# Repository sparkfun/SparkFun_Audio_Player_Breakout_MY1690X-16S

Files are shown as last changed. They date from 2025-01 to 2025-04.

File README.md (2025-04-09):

SparkFun Audio Player Breakout - MY1690X-16S
========================================

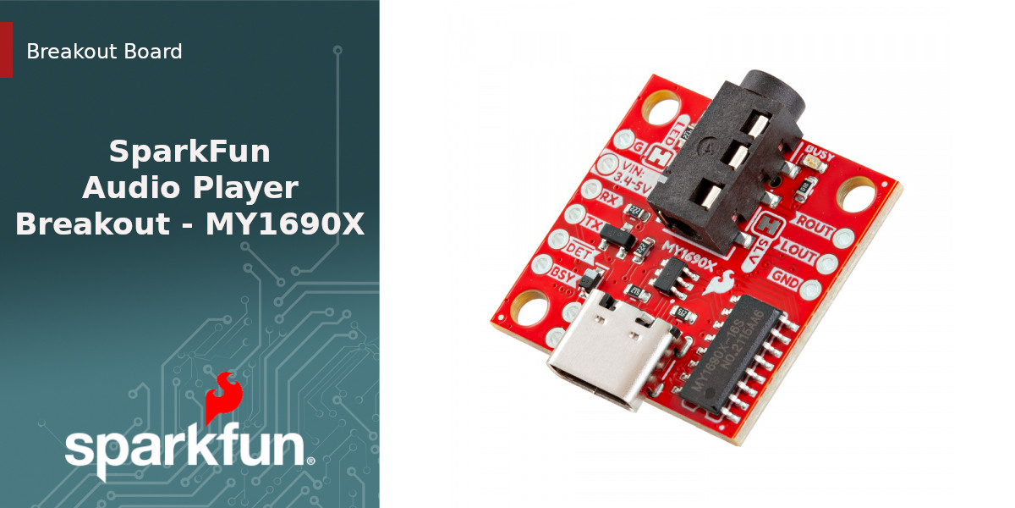
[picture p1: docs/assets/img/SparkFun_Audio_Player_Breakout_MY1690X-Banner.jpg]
SparkFun Audio Player Breakout - MY1690X-16S (https://www.sparkfun.com/sparkfun-audio-player-breakout-my1690x-16s.html)


[*SparkFun Audio Player Breakout - MY1690X-16S (BOB-28038)*](https://www.sparkfun.com/sparkfun-audio-player-breakout-my1690x-16s.html)

The SparkFun M71690X-16S Audio Player Breakout is a compact serial-controlled audio player designed around the MY1690X-16S decoder that supports both .WAV and .MP3 audio files played from a connected microSD card formatted to FAT16 or FAT32. The board includes a USB-C connector to mount it as a removable USB drive on a connected computer, a µSD card slot for connecting a compatible SD card, and a 3.5mm TRRS connector for headphone audio output.

Repository Contents
-------------------

* **.github/workflows** - YAML files used for GitHub Actions and GitHub Pages/mkdocs
* **/Hardware** - KiCad design files (.kicad_pcb, .kicad_sch, .kicad_pro)
  * **/Production** - Production panel files (.kicad_pcb)
* **/docs** - Online documentation files
  * **/assets** - Folder containing all the file assets used for product documentation
    * **/board_files** - Copy of design files used for product documentation
    * **/component_documentation** - Datasheets and manuals for hardware components
    * **/img** - Images for product documentation
  * **/github** - Files stating how to contribute and filing issues used for product documentation
  * **/javascript** - Folder containing custom javascript used for product documentation
  * **/stylesheet** - Folder containing CSS files used for product documentation
* **/overrides** - Customization files used for product documentation
  * **/.icons** - Icons used for GitHub used for product documentation
  * **./partials** - Used for product documentation

Documentation
--------------
* **[SparkFun MY1690X MP3 Decoder Arduino Library](https://github.com/sparkfun/SparkFun_MY1690_MP3_Decoder_Arduino_Library)** - Arduino library for the MY1690X MP3 Decoder.
* **[Hookup Guide](https://docs.sparkfun.com/SparkFun_Audio_Player_Breakout_MY1690X-16S)** - Basic hookup guide for the SparkFun Serial Audio Player Breakout - MY1690X.

Product Versions
----------------
* [BOB-28038](https://www.sparkfun.com/sparkfun-audio-player-breakout-my1690x-16s.html) - v1.0

License Information
-------------------

This product is _**open source**_!

Please review the LICENSE.md file for license information.

If you have any questions or concerns on licensing, please contact technical support on our [SparkFun forums](https://forum.sparkfun.com/viewforum.php?f=152).

Distributed as-is; no warranty is given.

- Your friends at SparkFun.

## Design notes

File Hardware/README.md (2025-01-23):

SparkFun <PRODUCT NAME> Design Files
=====================================

The .sch and .brd files hare are Eagle CAD schematic and PCB design files from SparkFun Electronics.
A freeware version of Autodesk Eagle can be found [here](https://www.autodesk.com/products/eagle/free-download).

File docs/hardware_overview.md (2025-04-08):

Let's take a closer look at the SparkFun Audio Player Breakout - MY1690X and the hardware present on the board. The photo below highlights the major components on this shield that we'll cover in more detail in this section:

<center>
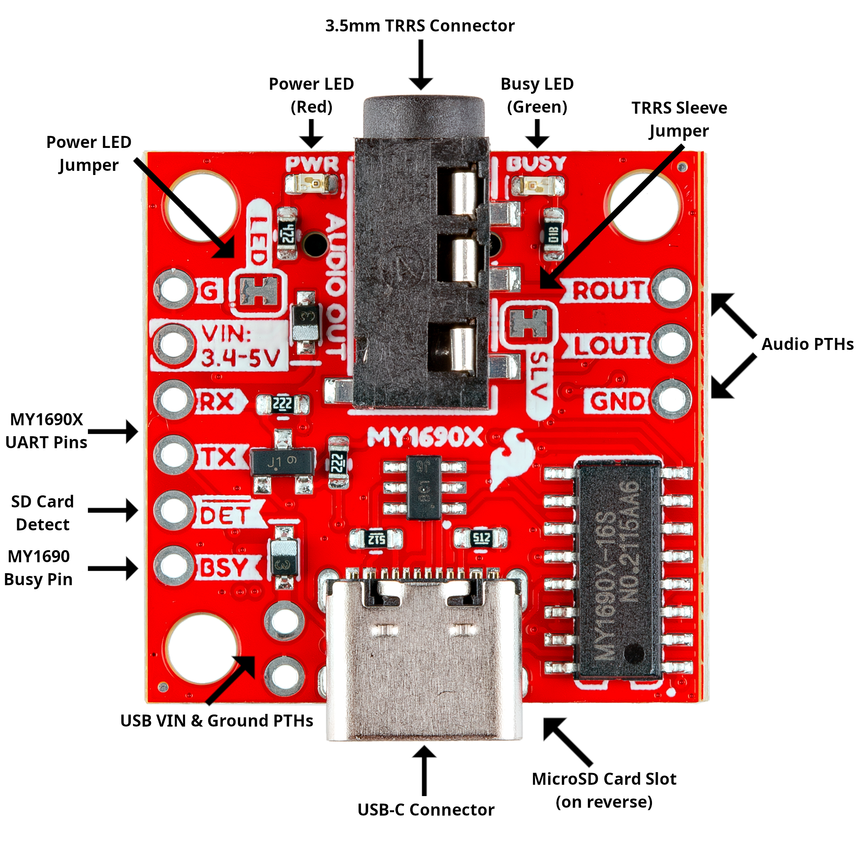
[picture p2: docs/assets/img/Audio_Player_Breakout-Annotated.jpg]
Annotated photo of audio player breakout

</center>

## MY1690X MP3 Decoder IC

The MY1690X is an MP3 decoder IC that works with both MP3 and WAV audio files stored on a connected &micro;SD card. The MY1690X can function both as a removable USB drive when connected over USB to load, view or edit files on the SD card. The IC operates over a serial-UART interface at 3.3V TTL using a command set to control audio playback (Play, Pause, Next, etc.), volume and equalizer settings and query statuses (SD card contents, track name/length, etc.). It supports audio files with sampling rates between 8 and 48k with bit rates between 8 and 320Kbps.

## Connectors

The Audio Player Breakout - MY1690X has a pair of connectors on the board. A USB-C connector and 3.5mm TRRS connector.

### USB-C

The USB-C connector on the board connects directly to the MY1690X to mount it as a removable USB drive when a microSD card is inserted and the board is plugged into a computer. This allows you to directly add and remove audio files to a connected microSD card. This works great for small audio files but in our testing we found the transfer speed is quite slow and can take several minutes to upload larger audio files. We recommend uploading large files using a USB SD card reader or directly connecting your SD card to your computer.

When connected over USB-C (and with a microSD card plugged in) the MY1690X will stay in USB drive "mode" until a power cycle. The MY1690X does not have a Reset line so either unplug the board or press the RESET button on the shield to cycle power.

## Audio Output

The shield routes the audio output from the MY1690X to a 3.5MM TRRS audio connector as well as three 0.1"-spaced through hole pins. This allows you to easily plug in a pair of headphones directly to the shield or solder an alternate audio output. Note, the MY1690X can easily output audio for small headphones but you'll need an external amplifier on the audio output to drive larger speakers.

## MicroSD Card Slot

The audio player breakout's microSD card slot works with most standard SD cards that have up to 32GB storage space and formatted to FAT16 or FAT32. The MY1690X requires specific naming of files and folders stored on the card. Read on to the MicroSD Card Setup section of this guide for detailed information on naming conventions.

## Power

The Audio Player Breakout has two primary ways for powering during normal (not USB drive) operation through the **VIN** and **VUSB** PTHs. Both of these pins are netted with VCC for the MY1690X and **3.4 and 5V**. The **VUSB** pin is also tied to the USB-C connector so it can be used either as a 5V power output with USB-C connector or as a power input while USB-C is **not** connected.

The USB-C connector can provide power to the board but the MY1690X defaults to operate as a removable drive when it detects a connection to the D+/- pins USB signals. 

## Pinout

The board breaks out the MY1690X's serial-UART pins (TX and RX), SD card detect, busy signal and power pins (VIN and GND) on one side and the audio output (Left, Right and Ground) on the opposite side. It also includes pins for VUSB and Ground next to the USB-C connector. The MY1690X communicates at 3.3V but the board has built-in level shifting to work with 5V logic boards.  

## LEDs

The board has a pair of LEDs labeled **PWR** and **BUSY**. The red Power LED indicates when the board has power. The green Busy LED indicates when the MY1690X is busy playing audio.

## Solder Jumpers

The Audio Player Breakout has three solder jumpers labeled **BUSY**, **PWR** and **SLV**. The **BUSY** and **PWR** solder jumpers complete the circuit for their respective LEDs and are CLOSED by default. Open them to disable these LEDs. The **SLV** jumper connects the sleeve pin of the TRRS connector to ground and is CLOSED by default. Open this jumper to free up the sleeve of the TRRS connector/cable. Most headphones with built-in mics send the MIC signal on the sleeve of their TRRS connector.

## Board Dimensions

The Audio Player Breakout measures 1" x 1" (25.4mm x 25.4mm) with three mounting holes that fit a [4-40 screw](https://www.sparkfun.com/screw-phillips-head-1-4-4-40-10-pack.html).

<center>
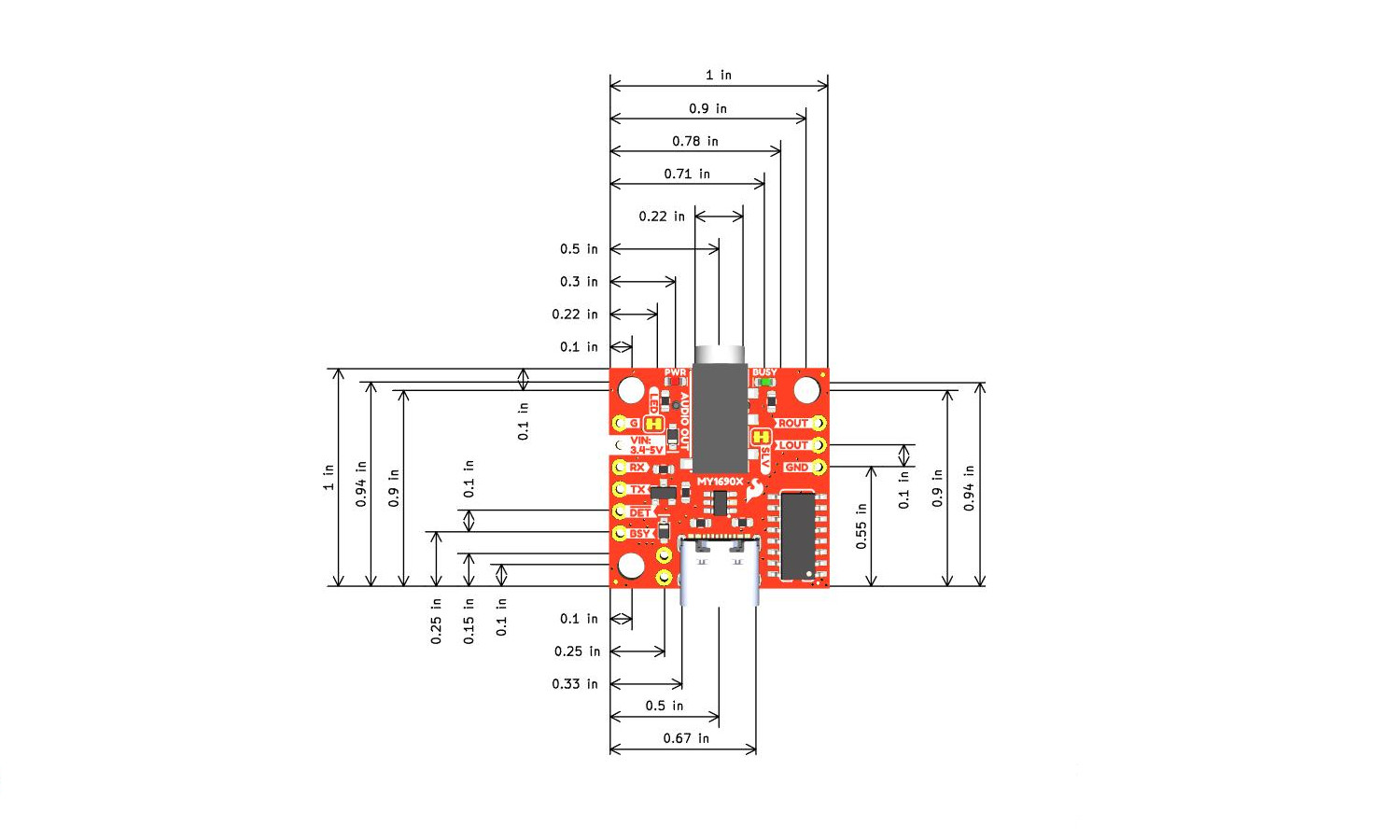
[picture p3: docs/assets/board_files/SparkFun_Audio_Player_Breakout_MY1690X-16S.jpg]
Board dimensions

</center>

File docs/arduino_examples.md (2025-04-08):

The SparkFun MY1690 MP3 Decoder Arduino library includes three examples to demonstrate how to use the library. Let's take a closer look at these examples.

## Example 1 - Play File

The first example plays the first audio track stored on a connected SD card once through and stops. In Arduino, open the example by navigating to **File** > **Examples** > **SparkFun MY1690X MP3 Decoder Arduino Library** > **Example1_PlayFile**. Select the **Board** and **Port** and click "Upload". Once upload finishes, the code will automatically start by playing the first track stored on the SD card so make sure to have headphones/speakers connected to hear the audio as it does not repeat. You can push the Reset button on the shield to reset the board and start the code over to hear the track play again.

The code does have some serial printouts to help troubleshoot if the code hangs on attempting to initialize the MY1690X or when checking the SD card for audio tracks. If you have any issues with playback, open the [serial monitor](https://docs.arduino.cc/software/ide-v2/tutorials/ide-v2-serial-monitor/) with the baud set to **115200** to view the serial prints from the code.

## Example 2 - Kitchen Sink

The second example demonstrates how to use all of the available commands on the MY1690X to control and manipulate audio tracks through a serial menu. Open the example by navigating to **File** > **Examples** > **SparkFun MY1690X MP3 Decoder Arduino Library** > **Example2_KitchenSink**. Select the **Board** and **Port** and click "Upload". After the code finishes uploading, open the serial monitor with the baud set to **115200** and you should see a menu like the screenshot below:

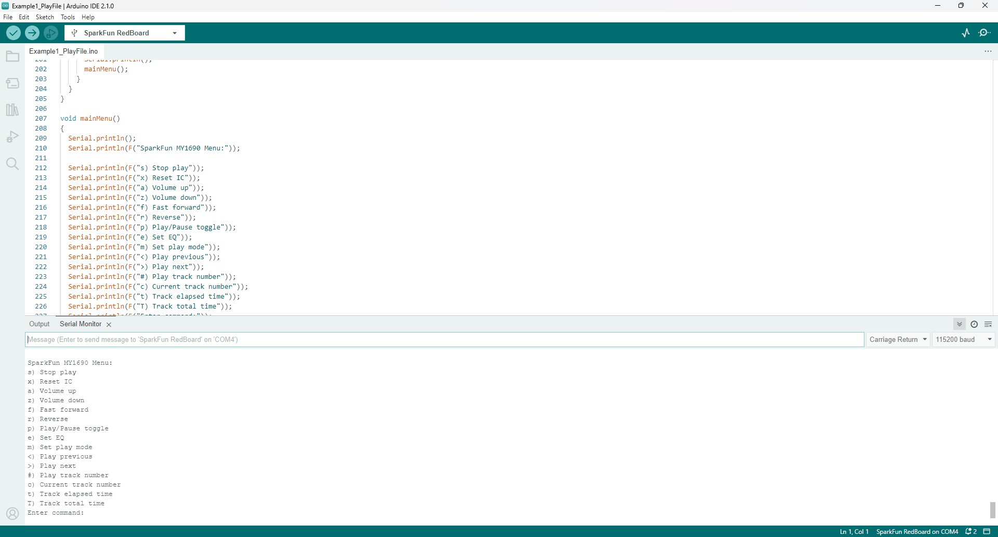
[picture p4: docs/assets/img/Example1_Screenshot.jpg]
Screenshot of example 2 serial menu


The MY1690 Menu has options for all the available playback and settings commands for the MY1690X. Some like "Play" or "Reverse" are straightforward and perform the expected action. The options for setting the equalizer (Set EQ) and play mode (Set Play Mode) cycle through the available options for these settings and print out the matching number. The Equalizer and Play modes are listed below and can be found in the instruction list in section 6.1 of the [MY1690X datasheet](./assets/component_documentation/MY1690X‑16S%20MP3%20Decoder%20IC%20User%20Manual.pdf):

**Equalizer Modes**

* 0 - None
* 1 - Pop
* 2 - Rock
* 3 - Jazz
* 4 - Classic
* 5 - Bass

**Play Modes**

* 0 - Full
* 1 - Folder
* 2 - Single
* 3 - Random
* 4 - No Loop

## Example 3 - Kitchen Sink ESP32

Example 3 - Kitchen Sink ESP32 is nearly identical to Example 2 but is modified to work with ESP32-based development boards like the [SparkFun IoT RedBoard - ESP32](https://www.sparkfun.com/sparkfun-iot-redboard-esp32-development-board.html). Open the example by navigating to **File** > **Examples** > **SparkFun MY1690X MP3 Decoder Arduino Library** > **Example2_KitchenSink**. Select the **Board** (SparkFun IoT RedBoard - ESP32 or other ESP32 dev board) and **Port** and click "Upload". After the code finishes uploading, open the serial monitor with the baud set to **115200** to view the same serial menu as pictured above.

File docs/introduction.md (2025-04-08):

Banner photo for Audio Player Breakout - MY1690X

The SparkFun Audio Player Breakout - MY1690X is a compact audio player built around the MY1690X audio decoder IC. The MY1691X supports both .WAV and .MP3 audio files stored on a connected microSD card with up to 32GB capacity and formatted to FAT16 or FAT32. The MY1690X communicates over serial UART with a simple command set 

You'll need the following items to follow along with this tutorial:

* [SparkFun Audio Player Breakout - MY1690X](https://www.sparkfun.com/sparkfun-audio-player-breakout-my1690x.html)
* [SparkFun RedBoard Plus](https://www.sparkfun.com/sparkfun-redboard-plus.html) or other development board
* [Male Breakaway Headers](https://www.sparkfun.com/male-breakaway-headers.html) or other header type
* [USB-C Cable](https://www.sparkfun.com/reversible-usb-a-to-c-cable-0-8m.html)

This breakout does require soldering to work properly so you'll need a soldering iron and soldering accessories to assemble it into an Arduino circuit.

## Topics Covered

This document contains three main sections: **Quickstart Guide**, **Hardware** and **Software**. 

The Quickstart Guide assumes a working knowledge of how to assemble and use breakout boards with an Arduino development board along with the required software to program them for your project's needs. It covers a quick assembly and then jumps right into getting the necessary software packages installed to start uploading code in just a few short minutes.

The Hardware pages cover a hardware overview that provides a detailed overview of the Audio Player Breakout - MY1690X covering all the major components on the board in detail as well as a hardware assembly page which goes over the steps required to assemble and use the Audio Player Breakout with an Arudino board.

The Software pages give instructions on installing the SparkFun MY1690 MP3 Decoder Arduino and using the examples included in it.

## Resources and Documentation

You'll find the board design files (KiCad files & schematic), relevant documentation (datasheets, white papers, etc.) and other helpful links in the **Resources**. Lastly, the **Support** section includes a Troubleshooting page that includes any helpful tips specific to this board as well as information on how to receive technical support from SparkFun.

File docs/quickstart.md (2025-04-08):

In this Quick Start guide we'll connect the SparkFun Audio Player Breakout - MY1690X to a SparkFun RedBoard Plus and use the SparkFun MY1690X MP3 Decoder Arduino Library to play audio stored on a connected microSD card. 

If you're not familiar with using breakout and development boards or the Arduino IDE, refer to the [Hardware](./hardware_overview.md) & [Software](./arduino_setup.md) sections for a detailed overview of the board along with instructions on soldering to and connecting the breakout, installing and using the SparkFun MY1690X MP3 Decoder Arduino Library.

## Basic Assembly

Start by soldering your preferred connector or wire to the to the power and serial pins (GND, VIN, RX and TX) on the Audio Player Breakout. We opted to just solder to all the pins to plug it into a breadboard for easy prototyping like the photo below:

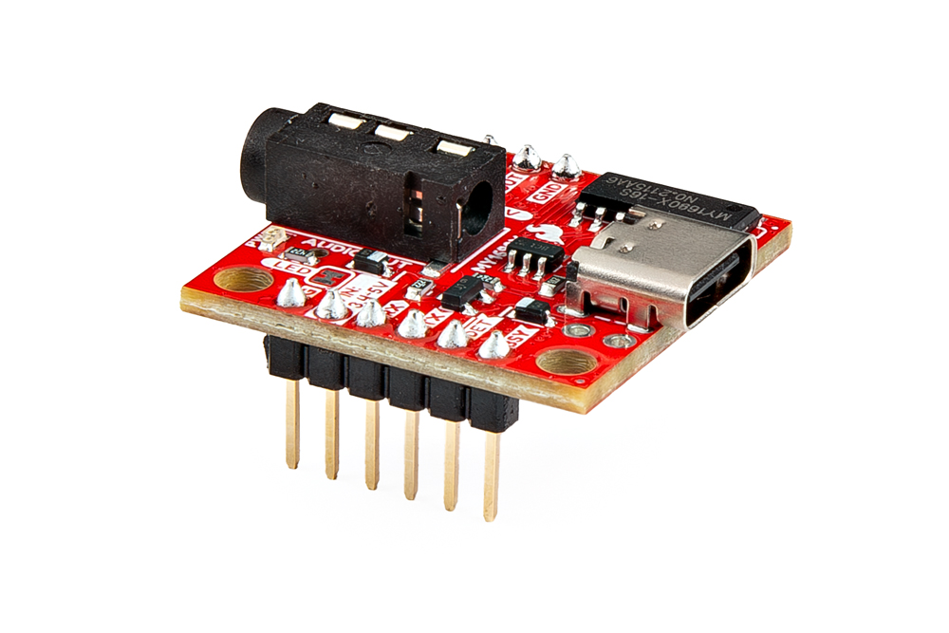
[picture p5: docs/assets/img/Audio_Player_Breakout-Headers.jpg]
Photo showing header pins soldered to the Audio Player Breakout


Next, make the following connections to your Arduino development board:

| Audio Player | Arduino |
| --- | --- |
| Ground | Ground  |
| VIN | 5V |
| RX | D9 |
| TX | D8 |

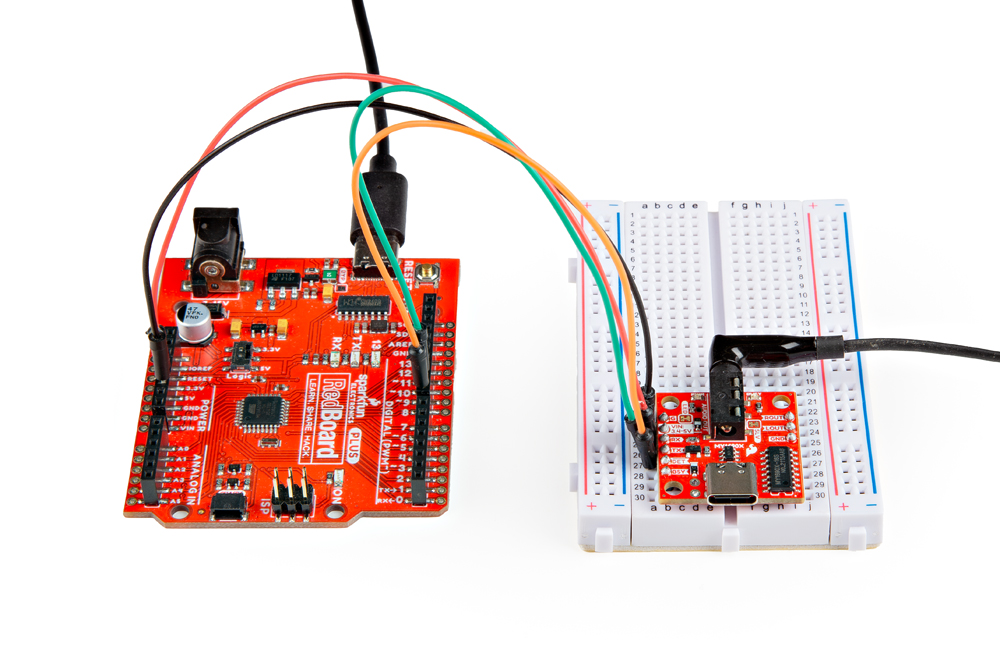
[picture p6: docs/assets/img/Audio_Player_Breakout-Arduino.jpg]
Photo showing Audio Player Breakout connected to RedBoard Plus


With everything wired up we can move on to preparing the SD card and uploading the example code.

## Prepare SD Card

The MY1690X works with standard SD cards up to 32GB capacity and formatted to either FAT16 or FAT32. Users can upload files to an SD card mounted on the shield by plugging it into a computer over USB-C or can load them directly onto the SD card using a USB Card Reader or the SD card slot on their computer. Files and folders on a connected SD card should match the following naming conventions:

* .MP3/.WAV files in the root directory must begin with a four digit number (eg. 000#) starting at 0001 and can have characters following the numbers
* Folders should begin with a two digit number (eg. 0#) starting at 01 and can have characters following the numbers.
* .MP3/.WAV files stored inside folders must begin with three digits (eg. 00#) starting at 001 and can have characters following the numbers.

Make sure to load the audio tracks onto the SD card, insert the card into the microSD card slot and then proceed to the Arduino Example.

## Arduino Example

With the audio player breakout connected to your development board, let's upload Example 2 - Kitchen Sink to the board to start playing and controlling audio. This example will start playing the first track once it's uploaded and also includes a serial menu to access all of the UART commands using simple text commands. Follow the steps below to upload the example.

* Open the [Arduino IDE](https://docs.arduino.cc/software/ide-v2/tutorials/getting-started-ide-v2/).
* Open the [Library Manager](https://docs.arduino.cc/software/ide-v2/tutorials/ide-v2-installing-a-library/) tool, search for "SparkFun MY1690X MP3 Decoder" and install the latest version 
* Open "Example 2 - Kitchen Sink".
* Select your Board (SparkFun RedBoard or other board) and Port and click "Upload".
* After the code compiles and finishes uploading, open the [serial monitor](https://docs.arduino.cc/software/ide-v2/tutorials/ide-v2-serial-monitor/) with the baud set to **115200**.
* The code prints out a menu of available commands to control the MY1690X's playback. Type in the command you'd like to do and hit Enter or click Send.
* Have fun playing around controlling track playback, volume and other features.

Screenshot of example 1 in Arduino

### Code to Note

* Serial Setup
``` c++
#include "SoftwareSerial.h"
SoftwareSerial serialMP3(8, 9); //RX on Arduino connected to TX on MY1690's, TX on Arduino connected to the MY1690's RX pin

//For boards that have multiple hardware serial ports
//HardwareSerial serialMP3(2); //Create serial port on ESP32: TX on 17, RX on 16
```
The code has options for both Software Serial and Hardware Serial depending on your dev board. The code defaults to use pins D8 and D9 for software serial

* MY1690X & Track Checks

```c++
if (myMP3.begin(serialMP3) == false) // Beginning the MP3 player requires a serial port (either hardware or software)
  {
    Serial.println(F("Device not detected. Check wiring. Freezing."));
    while (1);
  }

  int songCount = myMP3.getSongCount();
  if (songCount == 0)
  {
    Serial.println(F("Oh no! No songs found. Make sure the SD card is inserted and there are MP3s on it. Freezing."));
    while (1);
  }
```
On setup, the code checks to detect the MY1690X over serial and also checks to make sure the SD card has audio tracks 

* Get Track Numbers, MY1690 Version and Play First Track
```c++
  Serial.print(F("Number of tracks on SD card: "));
  Serial.println(songCount);

  Serial.print(F("MY1690 Version: "));
  Serial.println(myMP3.getVersion());

  myMP3.play(); //Will play the lowest numbered song in the folder
```

The example will print out the number of tracks detected on the SD card, the MY1690 version and then will play the lowest numbered song on the card. Note, it takes ~30ms for a track to start playing so the code waits 50ms before requesting play status.

* MY1690X Menu Options

This menu shows the available commands to control playback. Type in the matching character in the serial monitor and hit Enter to send it. The Set EQ and Set play mode commands cycle through the available equalizer and play mode options. Refer to the Arduino Examples section of this guide or section 6.1 of the [datasheet](./assets/component_documentation/MY1690X‑16S%20MP3%20Decoder%20IC%20User%20Manual.pdf) for more information.

```c++
void mainMenu()
{
  Serial.println();
  Serial.println(F("SparkFun MY1690 Menu:"));

  Serial.println(F("s) Stop play"));
  Serial.println(F("x) Reset IC"));
  Serial.println(F("a) Volume up"));
  Serial.println(F("z) Volume down"));
  Serial.println(F("f) Fast forward"));
  Serial.println(F("r) Reverse"));
  Serial.println(F("p) Play/Pause toggle"));
  Serial.println(F("e) Set EQ"));
  Serial.println(F("m) Set play mode"));
  Serial.println(F("<) Play previous"));
  Serial.println(F(">) Play next"));
  Serial.println(F("#) Play track number"));
  Serial.println(F("c) Current track number"));
  Serial.println(F("t) Track elapsed time"));
  Serial.println(F("T) Track total time"));
  Serial.println(F("Enter command:"));
}
```

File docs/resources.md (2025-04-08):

Refer to the following items for more information about the SparkFun Audio Player Breakout - MY1690X:

* [Schematic](./assets/board_files/SparkFun_Audio_Player_Breakout_MY1690X-16S.pdf)
* [KiCad Files](./assets/board_files/SparkFun_Audio_Player_Breakout_MY1690X-16S.zip)
* [Board Dimensions](./assets/board_files/SparkFun_Audio_Player_Breakout_MY1690X-16S.jpg)
* [Datasheet - MY1690X](./assets/component_documentation/MY1690X‑16S%20MP3%20Decoder%20IC%20User%20Manual.pdf)
* [SparkFun MY1690X MP3 Decoder Arduino Library](https://github.com/sparkfun/SparkFun_MY1690_MP3_Decoder_Arduino_Library)
* [GitHub Repository](https://github.com/sparkfun/SparkFun_Audio_Player_Breakout_MY1690X-16S)

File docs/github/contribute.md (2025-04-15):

# Contribute: Make an Augmentation!
Spot an improvement opportunity? Feel free to contribute to our open-source design and documentation. 

## :material-file-document-multiple:&nbsp;Improve our Documentation
All of this documentation can be modified by you! Please help us make it better.

* These pages are contained in the [`docs` folder](https://github.com/sparkfun/SparkFun_Audio_Player_Breakout_MY1690X-16S/tree/main/docs) of the [SparkFun IoT RedBoard repository](https://github.com/sparkfun/SparkFun_Audio_Player_Breakout_MY1690X-16S).

<!-- ### :material-source-pull:&nbsp;Submit a Correction -->
### Submit a Correction

1. With a GitHub account, [fork this repository](https://github.com/sparkfun/SparkFun_Audio_Player_Breakout_MY1690X-16S/fork).
2. Add your corrections or improvements to the markdown file.
3. File a pull request with your changes, and enjoy making the ~~words~~ ~~worlds~~ world a better place.
	* Once received, the documentation specialist will automatically be notified.
	* We will review your suggested improvements to make sure they are correct and fit within our documentation standards.

## :material-cog:&nbsp;Improve our Hardware Design
All of our designs are open-source! Please help us make it better.

* Our board design files are contained in the [`Hardware` folder](https://github.com/sparkfun/SparkFun_Audio_Player_Breakout_MY1690X-16S/tree/main/Hardware) of the [<Official Product Name> repository](https://github.com/sparkfun/SparkFun_Audio_Player_Breakout_MY1690X-16S).

<!-- ### :material-source-pull:&nbsp;Submit a Design Enhancement -->
### Submit a Design Enhancement

1. With a GitHub account, [fork this repository](https://github.com/sparkfun/SparkFun_Audio_Player_Breakout_MY1690X-16S/fork).
2. Add your design augmentation(s)
3. File a pull request with your changes, and enjoy making the ~~words~~ ~~worlds~~ world a better place.
	1. Once received, the engineer in charge of the original design will automatically be notified.
	2. We will review your suggested improvement(s) to verify that they are within our board design standards and meet our product design requirements.
	3. If approved, we will flag these changes for our next board revision. Congrats! 🍻

		!!! info
			Even if your suggestion is accepted, these changes may not be immediately available for purchase. We may have to cycle through our current product inventory first.

## Contributors&nbsp;:clap:
Let's provide some recognition to the contributors for this project!

GitHub Contributors Image
<br>


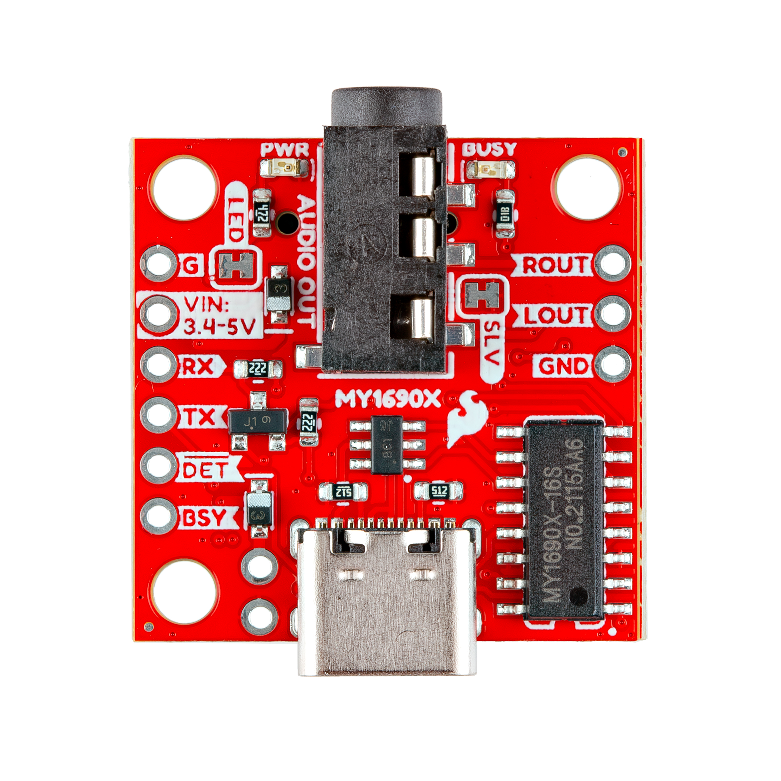
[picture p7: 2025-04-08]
docs/assets/img/28038-Audio-Player-Breakout-Front-high-res.jpg

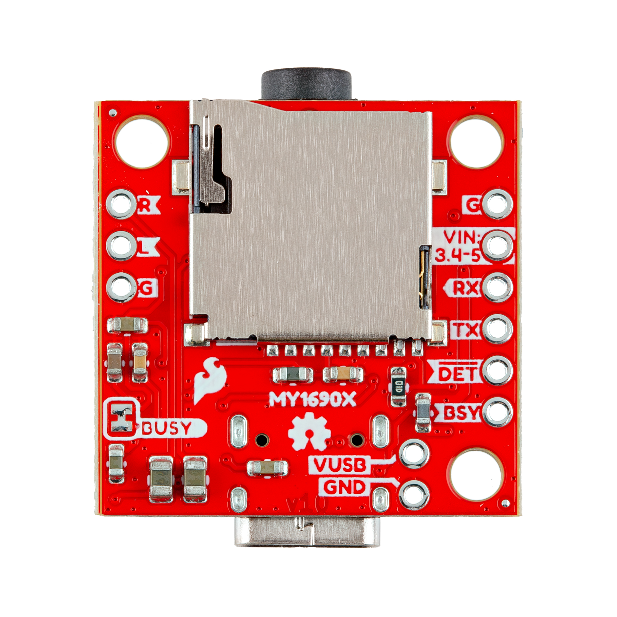
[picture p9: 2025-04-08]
docs/assets/img/28038-Audio-Player-Breakout-Back-high-res.jpg

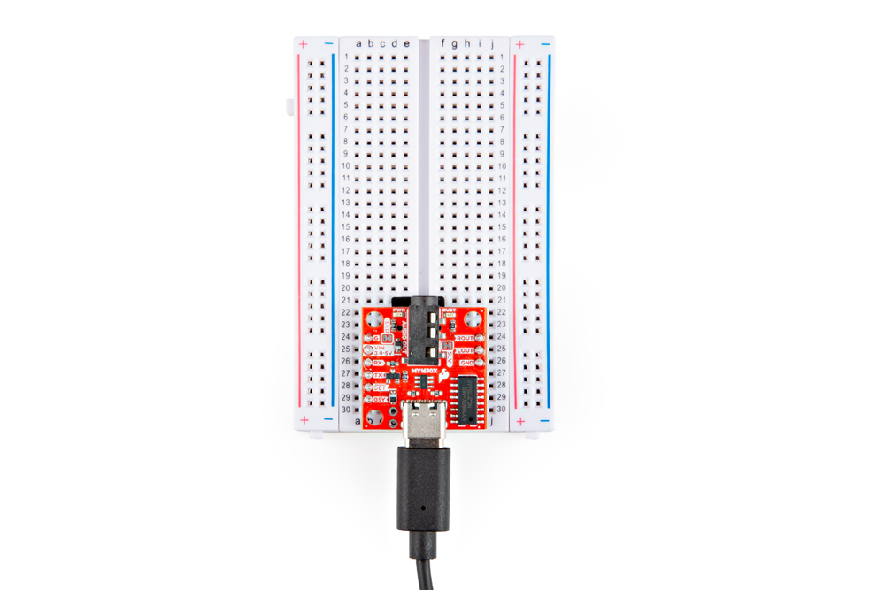
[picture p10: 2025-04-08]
docs/assets/img/28038-Audio-Player-Breakout-Action-21.jpg

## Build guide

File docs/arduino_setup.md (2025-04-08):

!!! arduino
    This example assumes you are using the latest version of the Arduino IDE on your desktop. If this is your first time using Arduino IDE, library, or board add-on, please review the following tutorials.

    - [Installing the Arduino IDE](https://learn.sparkfun.com/tutorials/installing-arduino-ide)
    - [Installing an Arduino Library](https://learn.sparkfun.com/tutorials/installing-an-arduino-library)
    - [Installing Board Definitions in the Arduino IDE](https://learn.sparkfun.com/tutorials/installing-board-definitions-in-the-arduino-ide)

## Installing the SparkFun MY1690X MP3 Decoder Arduino Library

The SparkFun MY1690X MP3 Decoder Arduino Library parses the MY1690X's full command set into a user-friendly menu controlled using a serial terminal. Install the library using the Arduino Library Manager tool by searching for "SparkFun MY1690X" and install the latest version. If you'd prefer to manually install the library, you can download it from the [GitHub Repository](https://github.com/sparkfun/SparkFun_MY1690_MP3_Decoder_Arduino_Library) or you can download a ZIP of the repository [here](https://github.com/sparkfun/SparkFun_MY1690_MP3_Decoder_Arduino_Library/archive/refs/heads/main.zip).

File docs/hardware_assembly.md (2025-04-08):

Start by soldering your preferred connector or wire to the to the power and serial pins (GND, VIN, RX and TX) on the Audio Player Breakout. We opted to just solder male headers to all the pins to plug it into a breadboard for easy prototyping like the photo below:

Photo showing header pins soldered to the Audio Player Breakout

Next, make the following connections to your Arduino development board:

| Audio Player | Arduino |
| --- | --- |
| Ground | Ground  |
| VIN | 5V |
| RX | D9 |
| TX | D8 |

Photo showing Audio Player Breakout connected to RedBoard Plus

Now that your Audio Player Breakout is wired up to your Arduino, let's move on to formatting and adding the audio tracks we'll be playing using the Arduino library.

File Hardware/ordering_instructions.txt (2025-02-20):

Ordering Instructions:
Panel dimensions: 116.80 x 84.05 mm.
Controlled Impedance: No
Material: TG135-140
Solder Mask: Red
Silkscreen Color: White
Layers: 4
Finish: Lead-free HASL
Thickness: 1.6mm
Outer Copper Weight: 1oz
Inner Copper Weight: 0.5oz
Minimum track width: 0.25mm (10.00mil)
Minimum via drill: 0.30mm (11.81mil)

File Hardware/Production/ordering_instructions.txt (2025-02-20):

Ordering Instructions:
Panel dimensions: 116.80 x 188.42 mm.
Controlled Impedance: No
Material: TG135-140
Solder Mask: Red
Silkscreen Color: White
Layers: 4
Finish: Lead-free HASL
Thickness: 1.6mm
Outer Copper Weight: 1oz
Inner Copper Weight: 0.5oz
Minimum track width: 0.25mm (9.70mil)
Minimum via drill: 0.30mm (11.81mil)

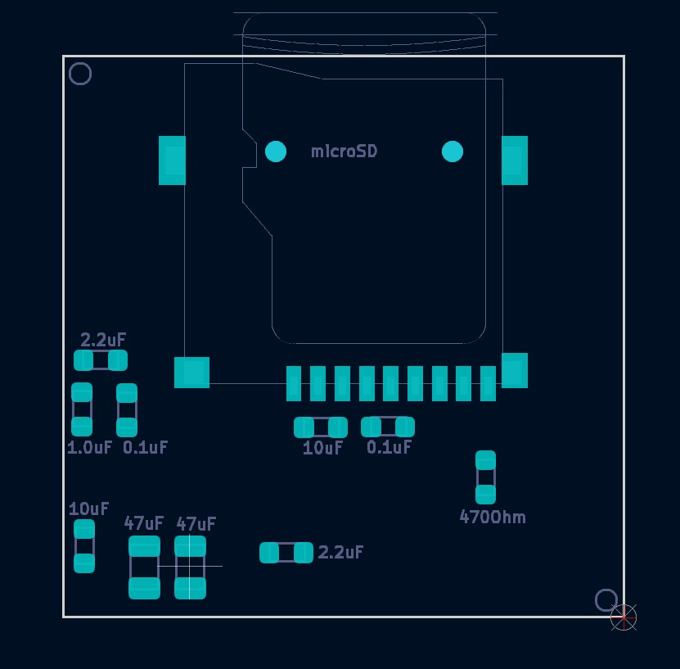
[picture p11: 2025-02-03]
Hardware/Assembly_Sheet_v01/SparkFun_Audio_Player_Breakout_MY1690X-16S_V01_ASSEMBLY_SHEET_BOTTOM.jpg

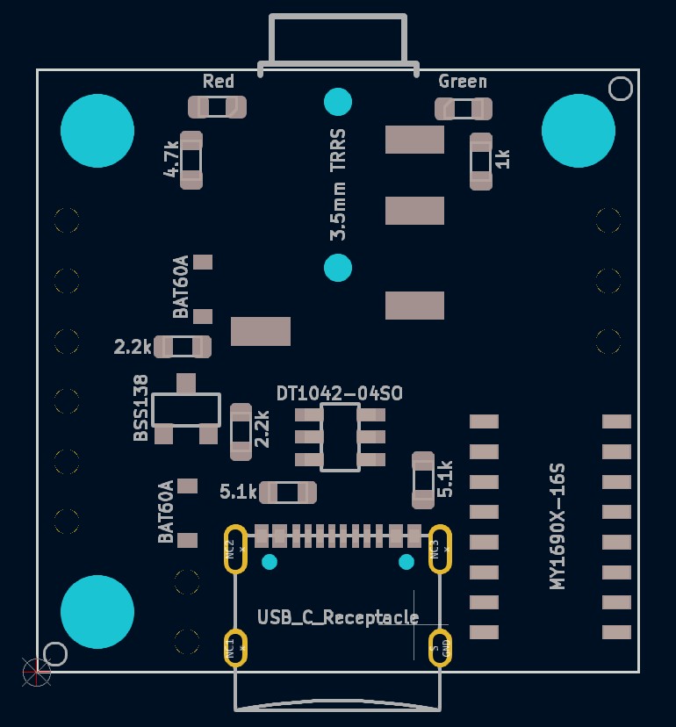
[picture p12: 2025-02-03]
Hardware/Assembly_Sheet_v01/SparkFun_Audio_Player_Breakout_MY1690X-16S_V01_ASSEMBLY_SHEET_TOP.jpg

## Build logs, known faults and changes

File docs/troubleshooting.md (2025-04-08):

## Audio Track Naming

One of the most common issues we expect you to run into will revolve around track naming outlined in the MicroSD Card Setup section of this guide and section 6.3 of the [datasheet](./assets/component_documentation/MY1690X‑16S%20MP3%20Decoder%20IC%20User%20Manual.pdf).Remember that tracks and folders must start at 0001 (Track in root directory), 001 (Track in folder) and 01 (Folder). Any tracks and folders not explicitly following the naming convention will be ignored by the MY1690X.

## General Troubleshooting Help

!!! note
    <span class="glyphicon glyphicon-question-sign" aria-hidden="true"></span>
        <strong> Not working as expected and need help? </strong> <br /><br />

    If you need technical assistance and more information on a product that is not working as you expected, we recommend heading on over to the <a href="https://www.sparkfun.com/technical_assistance">SparkFun Technical Assistance</a> page for some initial troubleshooting. <br /><br />

    <div style="text-align: center"><a href="https://www.sparkfun.com/technical_assistance" target="sfe_technical_assistance" class="md-button">SparkFun Technical Assistance Page</a></div>

    If you don't find what you need there, the <a href="https://community.sparkfun.com/">SparkFun Forums</a> are a great place to find and ask for help. If this is your first visit, you'll need to create a forum account to search product forums and post questions.<br /><br />

    <div style="text-align: center"><a href="https://community.sparkfun.com/" class="md-button md-button--primary">Log Into SparkFun Forums</a></div>

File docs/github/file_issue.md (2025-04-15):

# Did we make a mistake?

Spot something wrong? Please let us know. 

<!-- Technical Assistance Box -->
!!! warning "Need Help?"
    If you need technical assistance or more information on a product that is not working as you expected, we recommend heading on over to the [SparkFun Technical Assistance](https://www.sparkfun.com/technical_assistanc) page for some initial troubleshooting. This **Submit Issues** page is not where users should seek assistance.

    <center>
    [SparkFun Technical Assistance Page](https://www.sparkfun.com/technical_assistance){ .md-button .md-button--primary }
    </center>
    
    If you can't find what you need there, the [SparkFun Forums](https://forum.sparkfun.com/index.php) is a great place to search the product forums and ask questions.
    
    !!! info "Account Registration Required"
        For your first visit to our forum, you'll need to create a [Forum Account](https://forum.sparkfun.com/ucp.php?mode=register) to post questions.

## Discrepancies in the Documentation

All of our documentation can be modified by you! Please help us make it better.

* The documentation files for these pages are contained in the [`docs` folder](https://github.com/sparkfun/SparkFun_Audio_Player_Breakout_MY1690X-16S/tree/main/docs) of the [<Official Product Name> repository](https://github.com/sparkfun/SparkFun_Audio_Player_Breakout_MY1690X-16S).

### 🔍 Spot something wrong?

If a section of the documentation is incorrect, please [open an issue](https://github.com/sparkfun/SparkFun_Audio_Player_Breakout_MY1690X-16S/issues) and let us know.

### Do you have a suggested correction?

1. With a GitHub account, [fork this repository](https://github.com/sparkfun/SparkFun_Audio_Player_Breakout_MY1690X-16S/fork).
2. Add your correction(s) or improvement(s) to the markdown file(s)
3. File a pull request with your changes, and enjoy making the ~~words~~ ~~worlds~~ world a better place.
	* Once received, the documentation specialist will automatically be notified.
	* We will review your suggested improvement(s) to make sure they are correct and fit within our documentation standards.

## Problems in the Hardware Design

All of our designs are open-source! Please help us make it better.

* Our board design files are contained in the [`Hardware` folder](https://github.com/sparkfun/SparkFun_Audio_Player_Breakout_MY1690X-16S/tree/main/Hardware) of the [<Official Product Name> repository](https://github.com/sparkfun/SparkFun_Audio_Player_Breakout_MY1690X-16S).

### Does something not make sense? 🤔

If part of the design is confusing, please [open an issue](https://github.com/sparkfun/SparkFun_Audio_Player_Breakout_MY1690X-16S/issues) and let us know.

### Did we forget to include an important function of the board? 🤦

If part of the board's functionality is missing, please [open an issue](https://github.com/sparkfun/SparkFun_Audio_Player_Breakout_MY1690X-16S/issues) and file a feature request.

!!! tip "Design Considerations"
	Please keep in mind that we may intentionally exclude certain functions of the board to meet our product design requirements.
	
	* *For example, our Qwiic Micro boards are intended to fit on a small board layout and only use I<sup>2</sup>C communication; therefore, we may not have the SPI and interrupt pins available for users.*

### Do you wish to contribute directly to improving the board design?

1. With a GitHub account, [fork this repository](https://github.com/sparkfun/SparkFun_Audio_Player_Breakout_MY1690X-16S/fork).
2. Add your design augmentation(s)
3. File a pull request with your changes, and enjoy making the ~~words~~ ~~worlds~~ world a better place.
	1. Once received, the engineer in charge of the original design will automatically be notified.
	2. We will review your suggested improvement(s) to verify that they are within our board design standards and meet our product design requirements.
	3. If approved, we will flag these changes for our next board revision. Congrats! 🍻

		!!! info
			Even if your suggestion is accepted, these changes may not be immediately available for purchase. We may have to cycle through our current product inventory first.

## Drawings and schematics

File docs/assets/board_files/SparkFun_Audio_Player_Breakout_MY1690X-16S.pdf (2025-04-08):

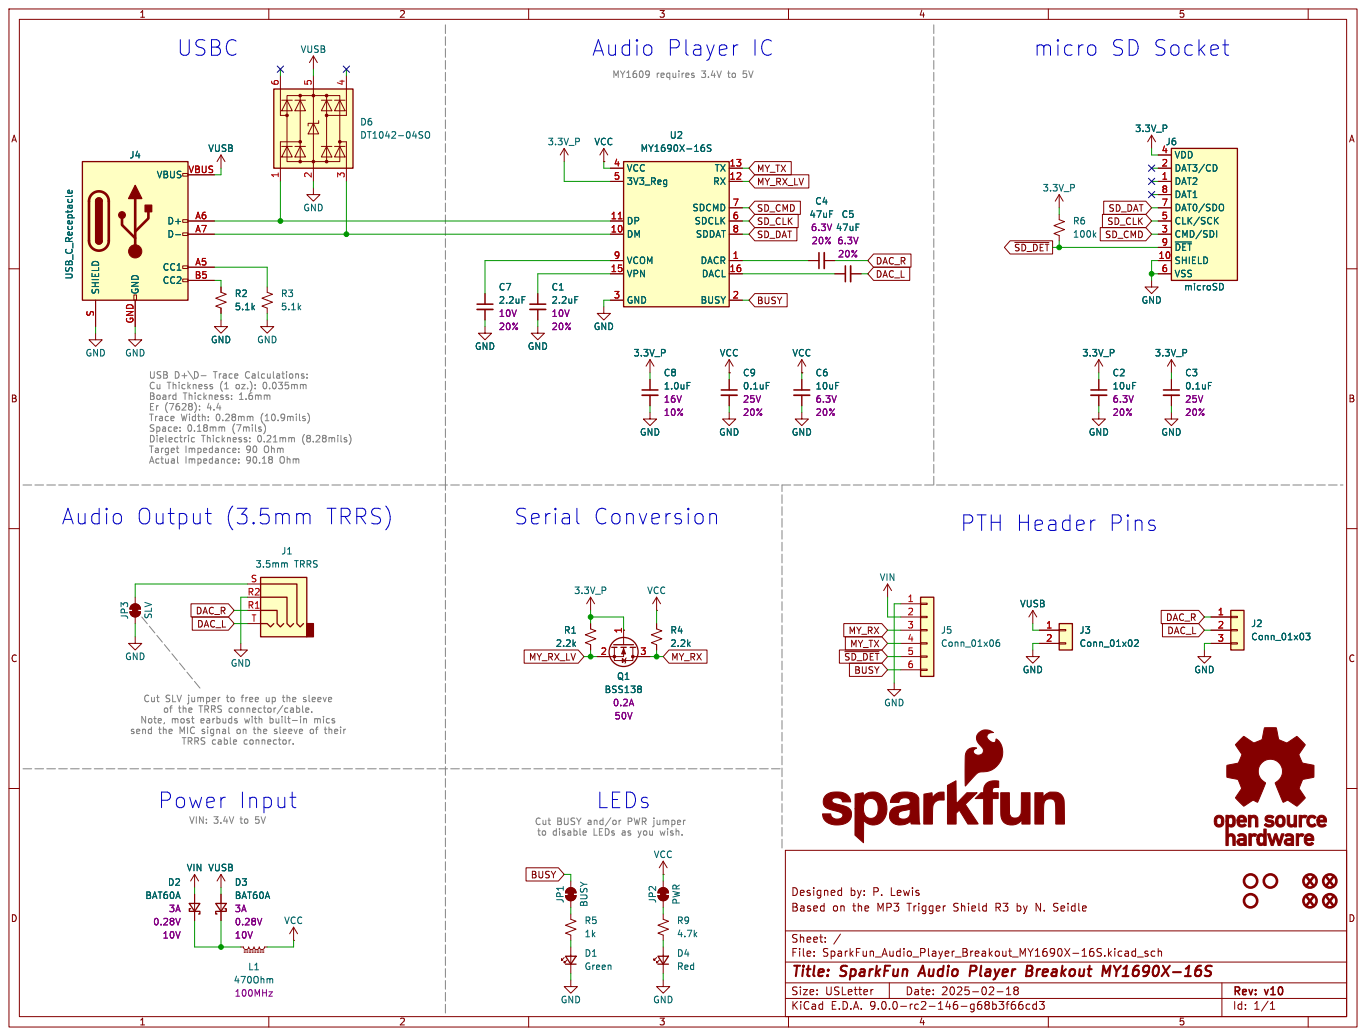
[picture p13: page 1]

to disable LEDs as you wish. Audio Output (3.5mm TRRS)

Power Input VIN: 3.4V to 5V Cut SLV jumper to free up the sleeve

send the MIC signal on the sleeve of their TRRS cable connector.

Id: 1/1 Title: SparkFun Audio Player Breakout MY1690X-16S

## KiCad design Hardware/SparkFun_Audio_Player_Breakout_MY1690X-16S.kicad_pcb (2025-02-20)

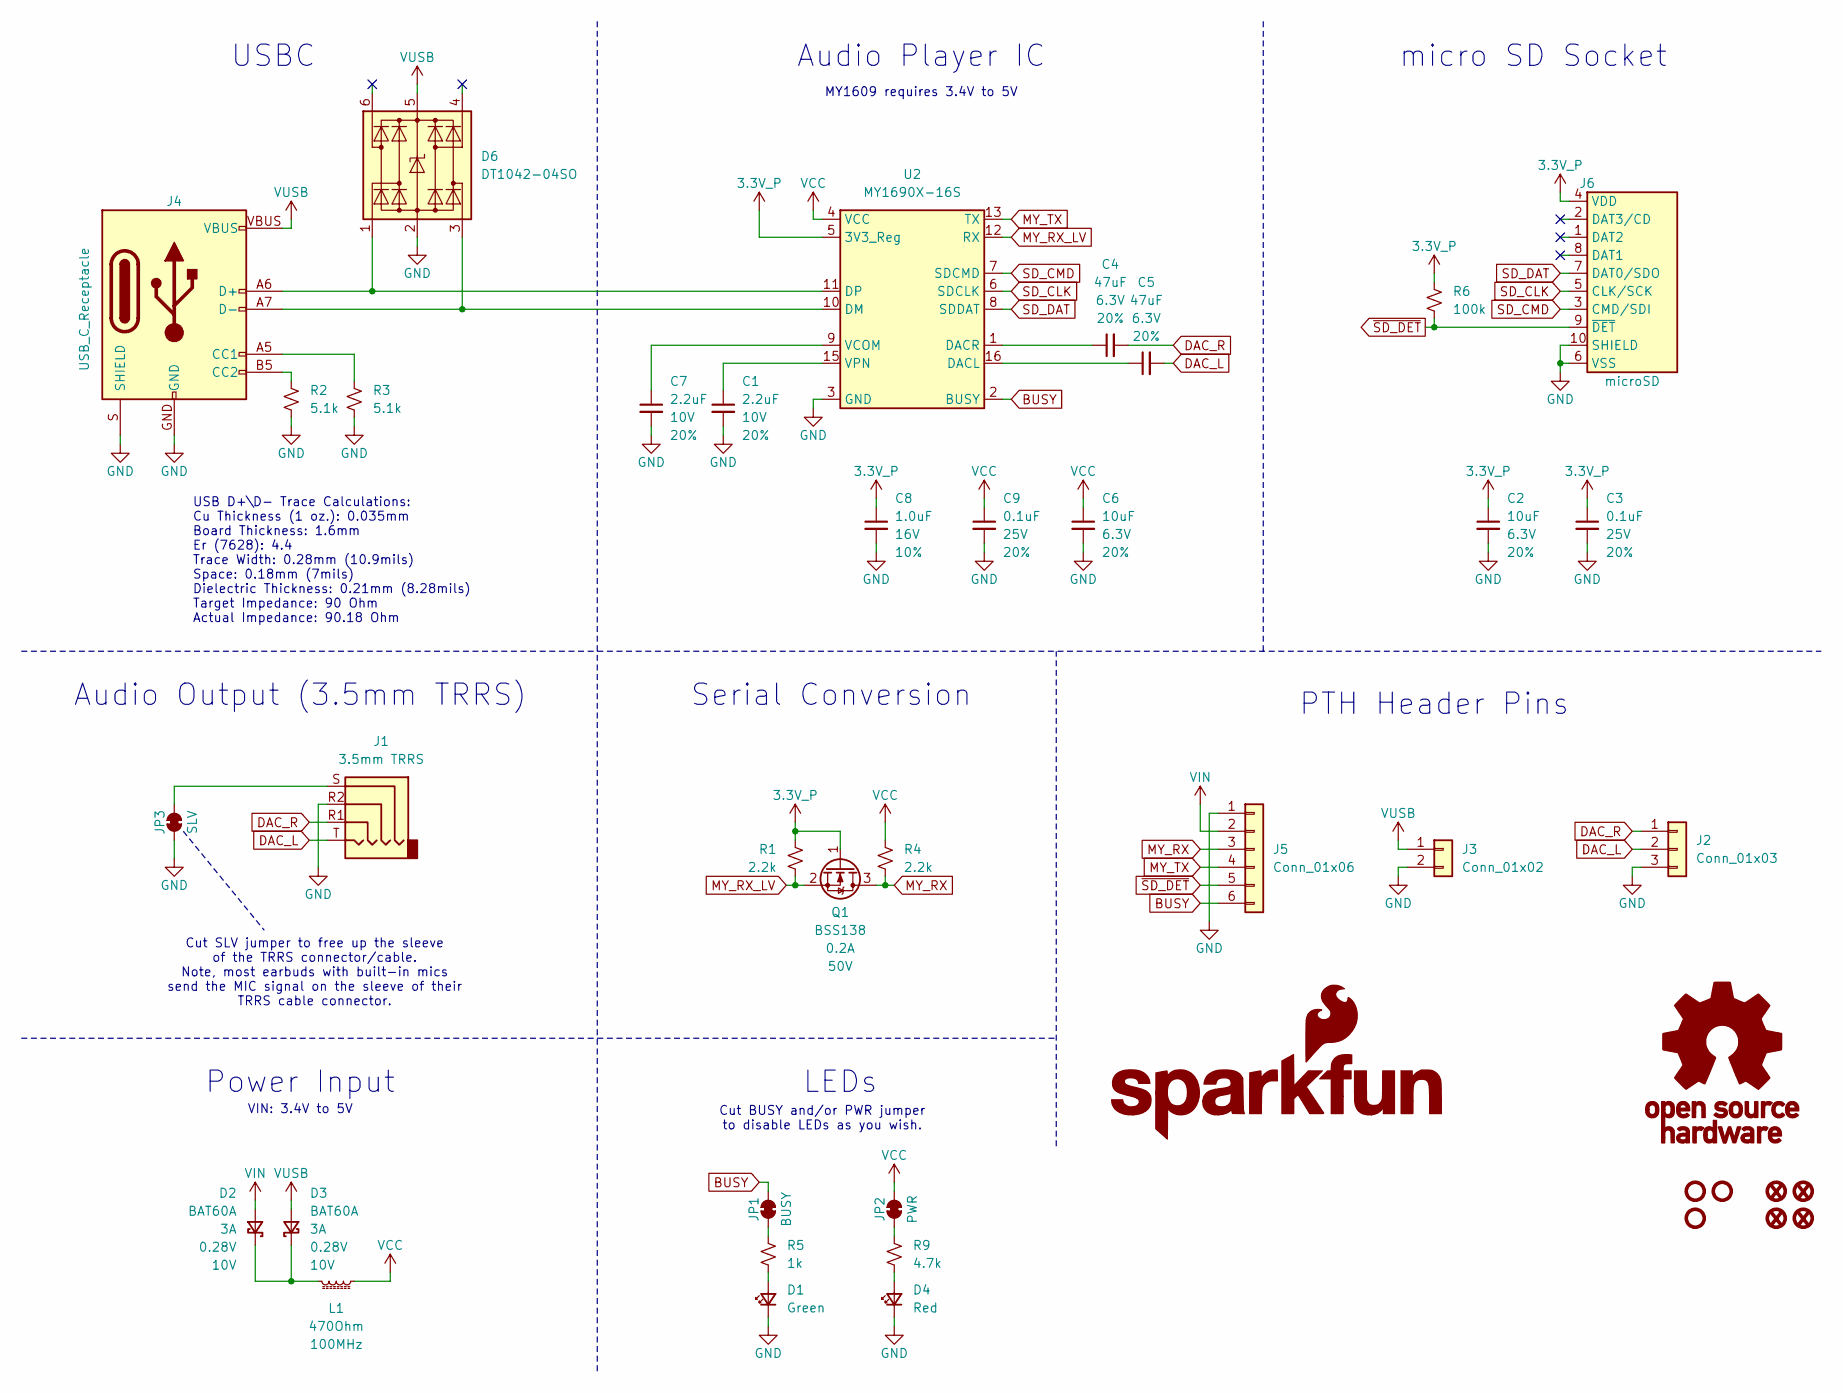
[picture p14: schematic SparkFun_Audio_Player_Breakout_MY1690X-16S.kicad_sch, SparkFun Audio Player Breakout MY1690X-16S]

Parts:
C1, C7: 2.2uF; C_0603_1608Metric; Voltage 10V; Tolerance 20%
C2, C6: 10uF; C_0603_1608Metric; Voltage 6.3V; Tolerance 20%
C3, C9: 0.1uF; C_0603_1608Metric; Voltage 25V; Tolerance 20%
C4, C5: 47uF; C_0805_2012Metric; Voltage 6.3V; Tolerance 20%
C8: 1.0uF; C_0603_1608Metric; Voltage 16V; Tolerance 10%
D1: Green; LED_0603_1608Metric_Green
D2, D3: BAT60A; SOD-323
D4: Red; LED_0603_1608Metric_Red
D6: DT1042-04SO; SOT23-6
FID1, FID2, FID3, FID4: Fiducial_0.5mm; Fiducial_0.5mm_Mask1mm
G1: OSHW_Logo; Creative_Commons_License
G5: SparkFun_Logo; SparkFun_Logo_8mm
J1: 3.5mm TRRS; Audio_Jack_3.5mm_TRRS_SMD_RA
J2: Conn_01x03; 1x03
J3: Conn_01x02; 1x02
J4: USB_C_Receptacle; USB-C_16
J5: Conn_01x06; 1x06
J6: microSD; microSD_External_Pin
JP1: BUSY; Jumper_2_NC_Trace
JP2: PWR; Jumper_2_NC_Trace
JP3: SLV; Jumper_2_NC_Trace
L1: 470Ohm; C_0603_1608Metric
Q1: BSS138; SOT23-3
R1, R4: 2.2k; R_0603_1608Metric
R2, R3: 5.1k; R_0603_1608Metric
R5: 1k; R_0603_1608Metric
R6: 100k; R_0603_1608Metric
R9: 4.7k; R_0603_1608Metric
ST1, ST2, ST3: Standoff
U2: MY1690X-16S; SO-16

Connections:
3.3V_P: C2.1, C3.1, C8.1, J6.4 (VDD), Q1.1 (G), R1.2, R6.1, U2.5 (3V3_Reg)
BUSY: J5.6, JP1.2 (B), U2.2 (BUSY)
DAC_L: C5.2, J1.T, J2.2
DAC_R: C4.2, J1.R1, J2.1
GND: C1.2, C2.2, C3.2, C6.2, C7.2, C8.2, C9.2, D1.1 (K), D4.1 (K), D6.2 (GND), J1.R2, J2.3, J3.2, J4.GND, J4.S (SHIELD), J5.1, J6.6 (VSS), J6.10 (SHIELD), JP3.1 (A), R2.2, R3.1, U2.3 (GND), U2.14 (GND)
MY_RX: J5.3, Q1.3 (D), R4.1
MY_RX_LV: Q1.2 (S), R1.1, U2.12 (RX)
MY_TX: J5.4, U2.13 (TX)
unnamed: D1.2 (A), R5.1
unnamed: D2.1 (K), D3.1 (K), L1.2
unnamed: D4.2 (A), R9.1
unnamed: D6.1 (I/O1), J4.A6 (D+), J4.B6 (D+), U2.11 (DP)
unnamed: D6.3 (I/O2), J4.A7 (D-), J4.B7 (D-), U2.10 (DM)
unnamed: J4.A5 (CC1), R3.2
unnamed: J4.B5 (CC2), R2.1
unnamed: JP1.1 (A), R5.2
unnamed: JP2.1 (A), R9.2
unnamed: J1.S, JP3.2 (B)
unnamed: C5.1, U2.16 (DACL)
unnamed: C4.1, U2.1 (DACR)
unnamed: C7.1, U2.9 (VCOM)
unnamed: C1.1, U2.15 (VPN)
SD_CLK: J6.5 (CLK/SCK), U2.6 (SDCLK)
SD_CMD: J6.3 (CMD/SDI), U2.7 (SDCMD)
SD_DAT: J6.7 (DAT0/SDO), U2.8 (SDDAT)
VCC: C6.1, C9.1, JP2.2 (B), L1.1, R4.2, U2.4 (VCC)
VIN: D2.2 (A), J5.2
VUSB: D3.2 (A), D6.5 (VCC), J3.1, J4.VBUS
~SD_DET: J5.5, J6.9 (~DET), R6.2

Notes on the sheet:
USBC
Serial Conversion
MY1609 requires 3.4V to 5V
Audio Output (3.5mm TRRS)
Cut BUSY and/or PWR jumper to disable LEDs as you wish.
micro SD Socket
Power Input
PTH Header Pins
Audio Player IC
LEDs
Cut SLV jumper to free up the sleeve of the TRRS connector/cable. Note, most earbuds with built-in mics send the MIC signal on the sleeve of their TRRS cable connector.
USB D+\D- Trace Calculations: Cu Thickness (1 oz.): 0.035mm Board Thickness: 1.6mm Er (7628): 4.4 Trace Width: 0.28mm (10.9mils) Space: 0.18mm (7mils) Dielectric Thickness: 0.21mm (8.28mils) Target Impedance: 90 Ohm Actual Impedance: 90.18 Ohm
VIN: 3.4V to 5V

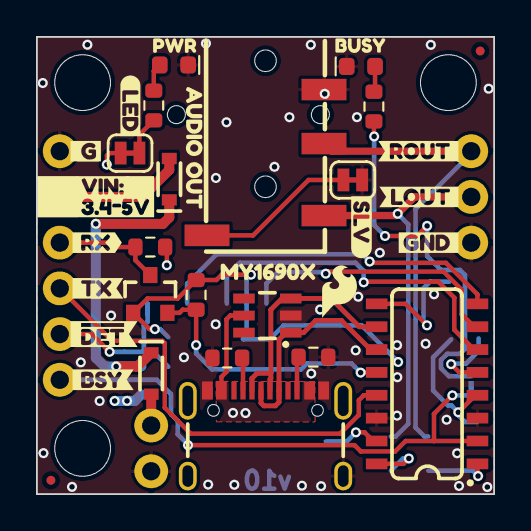
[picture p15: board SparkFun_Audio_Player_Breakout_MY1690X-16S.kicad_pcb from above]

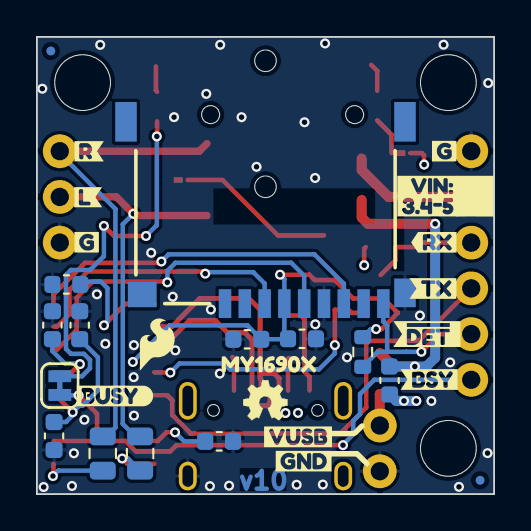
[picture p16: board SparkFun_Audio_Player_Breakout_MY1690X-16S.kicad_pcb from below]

Board: 4 copper layers, 25.4 x 25.4 mm, 72 parts (30 on the bottom side), 29 nets.

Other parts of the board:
Ref**: Val**; OSHW_Logo_2.5mm
kibuzzard-67AD02A2: G***; kibuzzard-67AD02A2
kibuzzard-67AD02AA: G***; kibuzzard-67AD02AA
kibuzzard-67AD03CF: G***; kibuzzard-67AD03CF
kibuzzard-67AD03ED: G***; kibuzzard-67AD03ED
kibuzzard-67B388A6: G***; kibuzzard-67B388A6
kibuzzard-67B391D1: G***; kibuzzard-67B391D1
kibuzzard-67B391E8: G***; kibuzzard-67B391E8
kibuzzard-67B394D8: G***; kibuzzard-67B394D8
kibuzzard-67B3920A: G***; kibuzzard-67B3920A
kibuzzard-67B38923: G***; kibuzzard-67B38923
kibuzzard-67B39233: G***; kibuzzard-67B39233
kibuzzard-67B39251: G***; kibuzzard-67B39251
kibuzzard-67B39267: G***; kibuzzard-67B39267
kibuzzard-6792C5B0: G***; kibuzzard-6792C5B0
kibuzzard-6792C5D2: G***; kibuzzard-6792C5D2
kibuzzard-6792C7DD, kibuzzard-6792C7DD#2: G***; kibuzzard-6792C7DD
kibuzzard-6792C876, kibuzzard-6792C876#2: G***; kibuzzard-6792C876
kibuzzard-6792CAB7: G***; kibuzzard-6792CAB7
kibuzzard-6792CAD9: G***; kibuzzard-6792CAD9
kibuzzard-6792CB45: G***; kibuzzard-6792CB45
kibuzzard-6792CB58: G***; kibuzzard-6792CB58
kibuzzard-6792CCE2: G***; kibuzzard-6792CCE2
kibuzzard-6792CD0E: G***; kibuzzard-6792CD0E
kibuzzard-6792CF5F: G***; kibuzzard-6792CF5F
kibuzzard-6792CF7B: G***; kibuzzard-6792CF7B
kibuzzard-6792CF8E: G***; kibuzzard-6792CF8E
kibuzzard-6798FF71: G***; kibuzzard-6798FF71
kibuzzard-679417DC: G***; kibuzzard-679417DC

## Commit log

2025-01-23 parts placed for a 1x1
    [SparkFun_Audio_Player_Breakout_MY1690X-16S.kicad_pcb, SparkFun_Audio_Player_Breakout_MY1690X-16S.kicad_sch]
2025-01-24 re-order header pins to put GND/VIN/RX/TX in a row
    [SparkFun_Audio_Player_Breakout_MY1690X-16S.kicad_pcb, SparkFun_Audio_Player_Breakout_MY1690X-16S.kicad_sch]
2025-01-24 TVS diode SOT23-6 package
    -for easier production/rework
    [SparkFun_Audio_Player_Breakout_MY1690X-16S.kicad_pcb, SparkFun_Audio_Player_Breakout_MY1690X-16S.kicad_sch]
2025-01-24 Routed v01 (pre-review)
    [SparkFun_Audio_Player_Breakout_MY1690X-16S.kicad_pcb, SparkFun_Audio_Player_Breakout_MY1690X-16S.kicad_sch]
2025-01-28 review changes 1
    -TX bottom silk fishtail (output)
    -centered position of OSHW logo
    -nudged vcc vias near VUSB pth headers for better ground flow pour
    -named JP3 "SLV"
    -added jumper comments to sch
    -moved C1/C8 to avoid text overlap in SCH
    -added RD to jumpers in sch
    -added NC flags to unused pins on SCH
    -measures
    [SparkFun_Audio_Player_Breakout_MY1690X-16S.kicad_pcb, SparkFun_Audio_Player_Breakout_MY1690X-16S.kicad_sch]
2025-01-28 removed R6 pull-down on uSD CLK line
    [SparkFun_Audio_Player_Breakout_MY1690X-16S.kicad_pcb, SparkFun_Audio_Player_Breakout_MY1690X-16S.kicad_sch]
2025-01-28 review changes 2
    -rotated LED jumper for easier access to cut when headers are populated
    -repositioned bottom passive components under the USB (now that R6 is gone). This allows bypass caps to be closer to uSD card pins.
    -updated frame info on brd and sch
    [SparkFun_Audio_Player_Breakout_MY1690X-16S.kicad_pcb, SparkFun_Audio_Player_Breakout_MY1690X-16S.kicad_sch]
2025-01-28 repositioned connectors to have over-hang
    [SparkFun_Audio_Player_Breakout_MY1690X-16S.kicad_pcb, SparkFun_Audio_Player_Breakout_MY1690X-16S.kicad_sch]
2025-01-29 checklist eng run
    -added ordering instruction about NPTH holes (under the TRRS connector)
    -sch cleanup
    -add VIN range in SCH and BRD
    -add "1234" text objects to each layer
    -nudges a via under LOUT silk
    [SparkFun_Audio_Player_Breakout_MY1690X-16S.kicad_pcb, SparkFun_Audio_Player_Breakout_MY1690X-16S.kicad_sch]
2025-01-29 Moved PCB version to under USB conn
    -it was getting blocked by the uSD card socket
    [SparkFun_Audio_Player_Breakout_MY1690X-16S.kicad_pcb]
2025-01-29 removed 1234 in copper
    [SparkFun_Audio_Player_Breakout_MY1690X-16S.kicad_pcb]
2025-01-29 one more via
    -added GND via next to double VCC via to inner plane
    [SparkFun_Audio_Player_Breakout_MY1690X-16S.kicad_pcb]
2025-01-29 prototype gerbers v01
    [SparkFun_Audio_Player_Breakout_MY1690X-16S.kicad_pcb]
2025-02-03 v01 assembly sheets - top & bottom
2025-02-17 Post-proto testing changes - v10
    -bumped version to v10 in sch and brd
    -added 3.4-5V in buzzard labels at the header pin
    -added over-bar to sd detect silk
    -added pullup resistor on sd detect
    -Move 3.3V_P trace elsewhere to avoid coupling and keep a complete plane (VCC) under the USB D+/D- lines.
    [SparkFun_Audio_Player_Breakout_MY1690X-16S.kicad_pcb, SparkFun_Audio_Player_Breakout_MY1690X-16S.kicad_sch]
2025-02-17 Sch cleanup
    -change title block texts to standard color and boldness
    [SparkFun_Audio_Player_Breakout_MY1690X-16S.kicad_sch]
2025-02-18 checklist reds eng v10
    -update measures
    -update kicad layer naming to new standards
    [SparkFun_Audio_Player_Breakout_MY1690X-16S.kicad_pcb]
2025-02-18 soldermask color RED
    [SparkFun_Audio_Player_Breakout_MY1690X-16S.kicad_pcb]
2025-02-18 updated version in page settings on PCB file
    [SparkFun_Audio_Player_Breakout_MY1690X-16S.kicad_pcb, SparkFun_Audio_Player_Breakout_MY1690X-16S.kicad_sch]
2025-02-19 USB trace tweaks
    -added USB trace calculations to SCH
    -general sch cleanup and spacing
    -adjusted USB data traces from 10mils to 9.7mils
    -adjusted USB data traces routing for proper 7mil gap
    [SparkFun_Audio_Player_Breakout_MY1690X-16S.kicad_pcb, SparkFun_Audio_Player_Breakout_MY1690X-16S.kicad_sch]
2025-02-19 updated layer names to new standards
    [SparkFun_Audio_Player_Breakout_MY1690X-16S.kicad_pcb]
2025-02-19 production panel and gerbers v10
    [SparkFun_Audio_Player_Breakout_MY1690X-16S_panelized.GBL, SparkFun_Audio_Player_Breakout_MY1690X-16S_panelized.GBO, SparkFun_Audio_Player_Breakout_MY1690X-16S_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]
2025-02-19 corrected USB trace width calcs
    -Prepeg is actually 8.28mils, not 7.1, according to Fab houses specs.
    -adjusted calcs/traces/gaps
    [SparkFun_Audio_Player_Breakout_MY1690X-16S.kicad_pcb, SparkFun_Audio_Player_Breakout_MY1690X-16S.kicad_sch]
2025-02-19 updated production panel and gerbers v10
    [SparkFun_Audio_Player_Breakout_MY1690X-16S_panelized.GBL, SparkFun_Audio_Player_Breakout_MY1690X-16S_panelized.GBO, SparkFun_Audio_Player_Breakout_MY1690X-16S_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]
2025-02-20 v10b gerbers
    -increased panel horizontal gaps from 0.2inches to 0.3inches for optimizing new AOI machine.
    -removed individual gerber files to clean up repo (only really need the ZIP)
    -renamed ZIP to include v10b, to keep versions straight on gerbers.
    -removed v10 older gerbers.
    [SparkFun_Audio_Player_Breakout_MY1690X-16S.kicad_pcb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]
2025-02-20 Ordering instructions updated - panel/gerber v10c
    -Material TG135-140
    -Controlled Impedance: No
    [SparkFun_Audio_Player_Breakout_MY1690X-16S.kicad_pcb]

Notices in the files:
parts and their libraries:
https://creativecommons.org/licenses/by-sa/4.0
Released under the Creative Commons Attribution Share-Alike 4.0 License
